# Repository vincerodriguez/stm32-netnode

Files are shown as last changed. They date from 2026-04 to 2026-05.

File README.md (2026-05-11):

# stm32-netnode

Usb powered stm32f407-based board that reports temperature and telemetry data over ethernet. BME688 is used for the temp sensor, with 1MB flash. SPI and I2C connectors for something in the future, good to have. 
## Status

- [x] Schematic complete
- [x] PCB layout complete  
- [x] v1 boards ordered from JLCPCB (2026-04-19)
- [x] Bring-up
- [x] Firmware MVP
- [x] Deployment

## Specs

| | |
|---|---|
| MCU | STM32F407VET6 (Cortex-M4F @ 168 MHz, 512 KB flash, 192 KB SRAM, 100-LQFP) |
| Ethernet PHY | Microchip LAN8720A, RMII |
| Magjack | Pulse J0011D01BNL |
| Sensor | Bosch BME688 (temperature, humidity, pressure, VOC) |
| Storage | Winbond W25Q80DVUXIE SPI NOR, 8 MBIT (1MB) |
| Power | USB-C, 5 V → 3.3 V via AP2112K-3.3 LDO |
| PCB | 60 × 60 mm, 4-layer, JLCPCB |
| Firmware | C - LWIP, ST-HAL (planned port to Rust) |

## Repo layout
hardware/ KiCad project structure
docs/ Design documentation and ADRs
firmware/ C firmware / Rust (coming soon)
test/ Bring-up checklists and general bring-up headaches

## Documents

- [Requirements](docs/01-design.md) *(coming)*
- [Architecture](docs/02-architecture.md) 
- [Decision records](docs/03-bringup-analysis.md) *(coming)*

## License

MIT

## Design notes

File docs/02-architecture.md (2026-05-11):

# Architecture

This document describes the architecture and firmware design for the stm32-netnode. See the [Design Decisions](01-design.md) for the *why* specific parts and patterns were chosen. For the story of how it actually came up, see [Bring-up Analysis](03-bringup-analysis.md).

---

## Hardware block diagram

MCU ->  ETHERNET
    |
    --> FLASH
    |
    --> TEMPERATURE
    |
    --> CONNECTIVITY (SWD/UART/I2C/SPI)
5V(USB) -> 3.3V LDO -> (MCU/PHY/FLASH/TEMP)

See hardware/[schematic.pdf]

## Subsystems

### Power

The boards main power input is 5V from USB-C. The AP2112K-3.3 max current is 600mA. We can safely assume the MCU and peripherals will pull much less than that, and will be safely below the 600mA limit of the AP2112K-3.3. 
Power estimation:
MCU: 100-150mA
PHY: 50-70mA
Temp Sensor: 3-12mA
Flash 5-15mA
Misc(LED/GPIO) 10-20mA
Then we could shoot for a max current consumption of around 270mA.
So if we design around the peak consumption of 270mA with every device being pushed to its limit we have around a 1.7V drop across the LDO, with dissipation being 459mW. At about 184°C/W for the SOT-25 package from the LDO datasheet, that gives around an 84.5°C rise above ambient. This will push the junction temp to around 110°C which is close to the absolute max of 125°C. With sufficient copper given to the LDO this should be manageable. For a later revision, a switching regulator would be a better choice if we add more peripherals and functionality.  

### Ethernet

I've used the LAN8720 in many designs before its selection was a no-brainer. The STM23F407 has a 10/100 Ethernet MAC, with RMII support, which will cut down on the number of pins. The LAN8720 supports 100Mbps and RMII. The PHY has distinct clocking configurations, you can either give it a 25MHz clock, and have it generate a 50Mhz reference to the MCU, or you can supply both the MCU and PHY a 50Mhz reference. For simplicity, and to choose a path I've known to work in the past, I chose the former. For the physical side, the J0011D01BNL with integrated magnetics is sufficient, as it will cut down on board space, since a dedicated magnetics component would not be needed, and it is used in the LAN8720 reference design.

### Storage

A modest 1MB (8Mbit) serial NOR flash is availiable for future logging or data storage. The price and availability of memory these seems to be continuing to rise, so a relatively cheap part is chosen, the W25Q80DVUXIE. Whichever SPI peripheral is available and makes routing the easiest is the best approach here. 

### Sensor

For the main purpose of the board, a popular and relatively cheap temperature/humidity/baro sensor is a great fit. The communication interface is I2C, with the address hard-coded by pullups/downs on specific pins (CSB pulled high chooses 0x77). Sensor readings don't have to be the fastest, so around 1Hz will be more than enough for a passive ambient room monitor. 

### Debug & programming

Main programmin interface will be a SWD header, with SWCLK, SWDIO, GND and RESET pins exposed. This allows debugging at the Cortex-M core. USB data will also be routed to the dedicated USB interface pins for DFU programming. UART DFU pins will not be routed, but perhaps will be in a future revision. DFU can be difficult based on previous designs. 

---

## Firmware architecture

Firmware will be first brought-up using STM's CubeMX generator. This will provide a basis for organization and STM's own HAL libraries. The Lightweight IP stack will be perfect for this boards intentions. There will need to be some dedicated review on how it works on my part, with the help of Claude code of course. Evetually the task will turn into porting over the firmware to Rust.  

### Overall structure

The big picture is that the firmware reads the temperature sensor once every second and serves the data as JSON over a raw LwIP HTTP server. Claude code was used to create a good-looking web dashboard that allows you to select which sensor reading you want displayed over time. The mainloop drives the TCP/IP stack takes in command line input from a UART connection to a PC, and reads the temperature sensor. 

### Module layout

```
firmware/Core/src/
├── main.c              # Main loop, init sequence
├── bme68x_driver.c     # Temp sensor driver using API  
├── bme68x.c            # Official Bosche API
├── cli.c               # Serial console command line driver 
├── http_server.c       # Claude-generated HTTP server 
├── lan8720.c           # PHY application API 
├── sensor_data.c       # Simple sensor API implementation
├── w25q80.c            # SPI NOR driver
```
### Concurrency model

Priority is implicit here, each call gets its own CPU time, no interrupts and no OS. Simple enough for a hardware engineer. Each process has to finish before the next gets a chance to do what it does. If a TCP packet arrives while the temp sensor is sending data it has to wait until Sensor_Poll() returns. The ethernet interface has a DMA FIFO so while other tasks are running the queue gets filled, but it's very inlikely that it will get full and drop packets before the loop comes back around and the ISR drains it. Perhaps if a sensor read takes a extrememly large amount of time to return, some packets might be dropped, but a coupple sensor readings a couple seconds apart being dropped does not matter in the grans scheme of this design. 

### Interrupt usage

The only interrupt driven process in this design is the ethernet DMA engine. TCP packets fill a RX buffer and it gets processed when the MX_LWIP_Process() gets called. The command line UART interface and temperature sensor readings are all blocking. You may notice some dropped input characters. The heartbeat LED would be the biggest indicator that something took longer than expected since its update is in the same loop as the blocking processes. 

### HTTP server

The HTTP server serves a html dashboard, sensor readings an JSON and the ability to toggle the gas sensor on or off to eliminated the temperature reading drift. Perhaps this could be optimized to be stored in the on-board flash, as it takes up about 7KB in the MCU flash. This does contribute to less SRAM footprint during the MCU runtime, but less MCU flash usage as well will be even better. The biggest RAM consumption would be the TCP RX buffers which would take up around 20-30KB. With 512KB of flash and 192KB of SRAM I have plenty of headroom.

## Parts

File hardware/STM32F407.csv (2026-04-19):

Id | Designator | Footprint | Quantity | Designation | Supplier and ref
1 | 3.3V, ETH_CRS_DV, ETH_REF_CLK, GND, GND, VUSB | TestPoint_Pad_D1.5mm | 6 | TestPoint
2 | C1, C2, C28 | C_0603_1608Metric | 3 | 10u
3 | C3, C9, C10, C11, C12, C13, C14, C16, C17, C18, C19, C23, C24, C25, C27, C29, C30 | C_0603_1608Metric | 17 | 0.1u
4 | C4, C15, C26 | C_0805_2012Metric | 3 | 4.7u
5 | C5, C6, C21, C22 | C_0603_1608Metric | 4 | 27pF
6 | C7, C8 | C_0603_1608Metric | 2 | 2u2
7 | C20 | C_0603_1608Metric | 1 | 0.022u 50V
8 | D1, D2 | LED_0603_1608Metric | 2 | LED
9 | D3 | LED_0603_1608Metric | 1 | POWER
10 | D4 | LED_0603_1608Metric | 1 | USER
11 | FB1 | L_0201_0603Metric | 1 | FerriteBead
12 | J1 | USB4110-GF-A_GCT | 1 | USB4110-GF-A
13 | J2 | CONN12_011D01BNL_PUL | 1 | J0011D01BNL
14 | J4 | PinHeader_2x10_P2.54mm_Vertical_SMD | 1 | Breakout
15 | R1, R2, R12, R15, R16, R17, R18, R26, R27 | R_0603_1608Metric | 9 | 10k
16 | R3, R4, R29, R30 | R_0603_1608Metric | 4 | 4.7k
17 | R6 | R_0603_1608Metric | 1 | 0
18 | R7, R8, R9, R10 | R_0603_1608Metric | 4 | 49.9 1%
19 | R11, R13 | R_0603_1608Metric | 2 | 270
20 | R14 | R_0603_1608Metric | 1 | 12.4k
21 | R19, R20, R21, R22, R23, R24, R25 | R_0603_1608Metric | 7 | 33
22 | R28 | R_0603_1608Metric | 1 | 1k
23 | R31, R32, R34, R35 | R_0603_1608Metric | 4 | 220
24 | R33, R38 | R_0603_1608Metric | 2 | 1.5k
25 | R36, R37 | R_0603_1608Metric | 2 | 5.1k
26 | SW1, SW2 | SW_7914J-1-000E | 2 | 7914J-1-000E
27 | U1 | LQFP-100_14x14mm_P0.5mm | 1 | STM32F407VETx
28 | U2 | Winbond_USON-8-1EP_3x2mm_P0.5mm_EP0.2x1.6mm | 1 | W25Q25PWSSIQ
29 | U3 | VQFN-24-1EP_4x4mm_P0.5mm_EP2.5x2.5mm_ThermalVias | 1 | LAN8720A
30 | U4 | IC_BME688 | 1 | BME688
31 | U5 | SILABS_CP2102N-A02-GQFN20R | 1 | CP2102N-A02-GQFN20R
32 | U6 | SOT-23-5 | 1 | AP2112K-3.3
33 | U7 | SOT-666 | 1 | USBLC6-2P6
34 | Y1 | Crystal_SMD_HC49-SD | 1 | 8MHz
35 | Y2 | Crystal_SMD_Abracon_ABM3B-4Pin_5.0x3.2mm | 1 | ABM3B-25.000MHZ-B2-T

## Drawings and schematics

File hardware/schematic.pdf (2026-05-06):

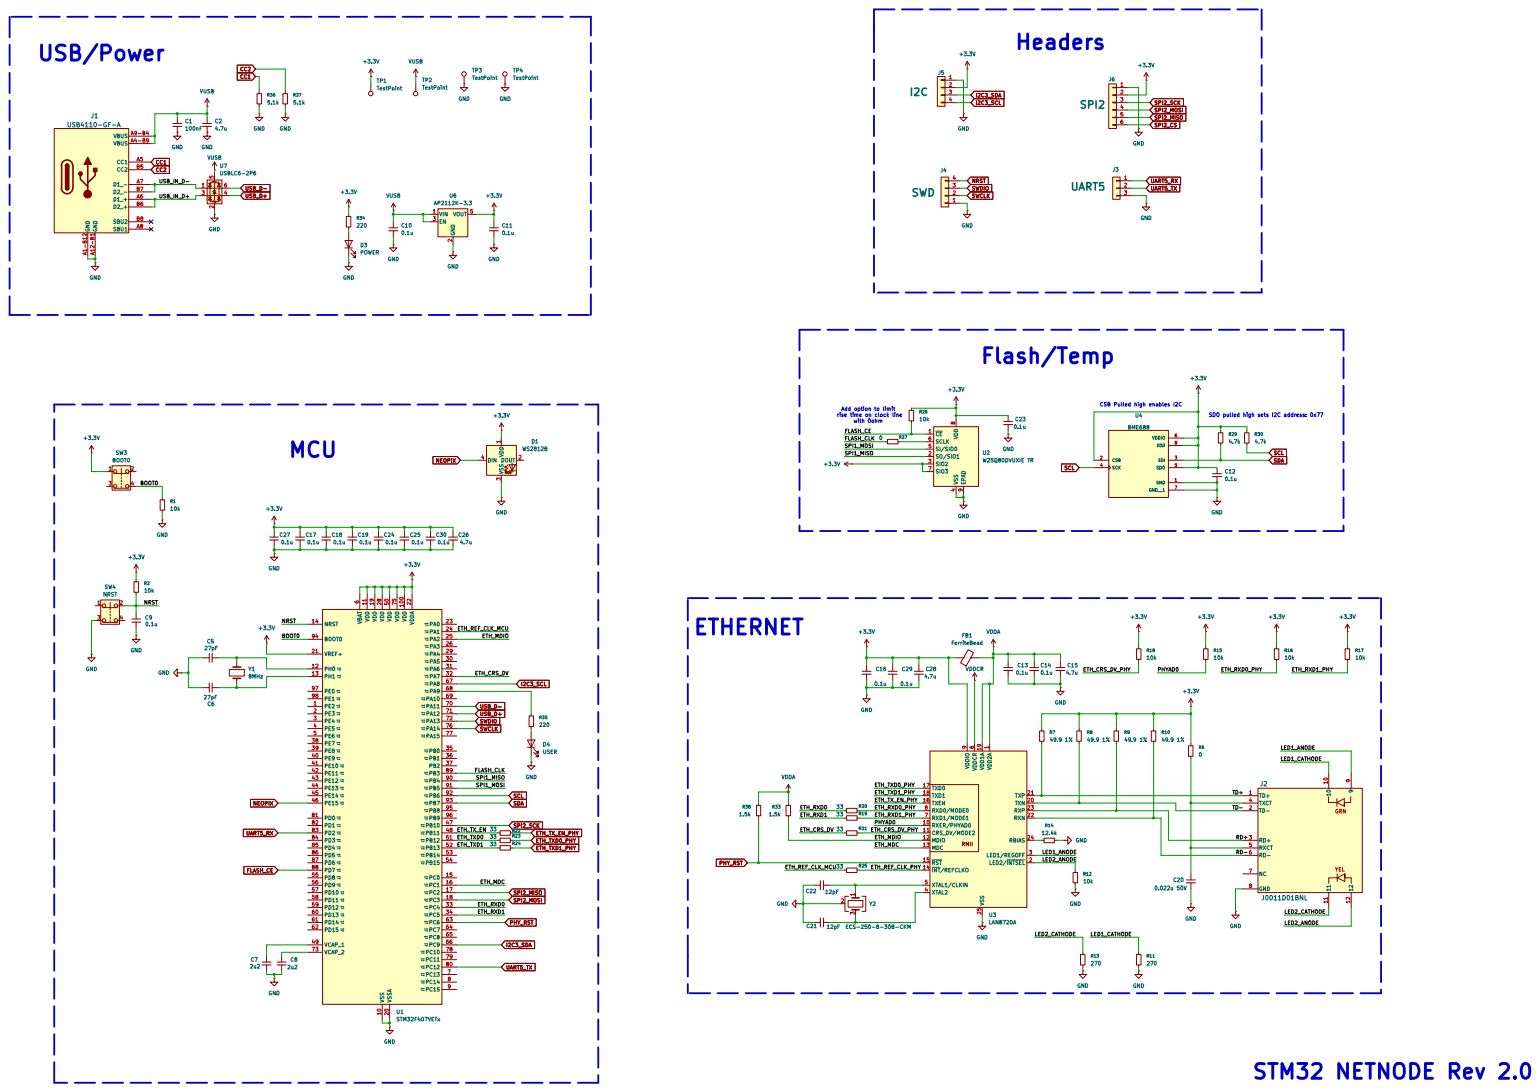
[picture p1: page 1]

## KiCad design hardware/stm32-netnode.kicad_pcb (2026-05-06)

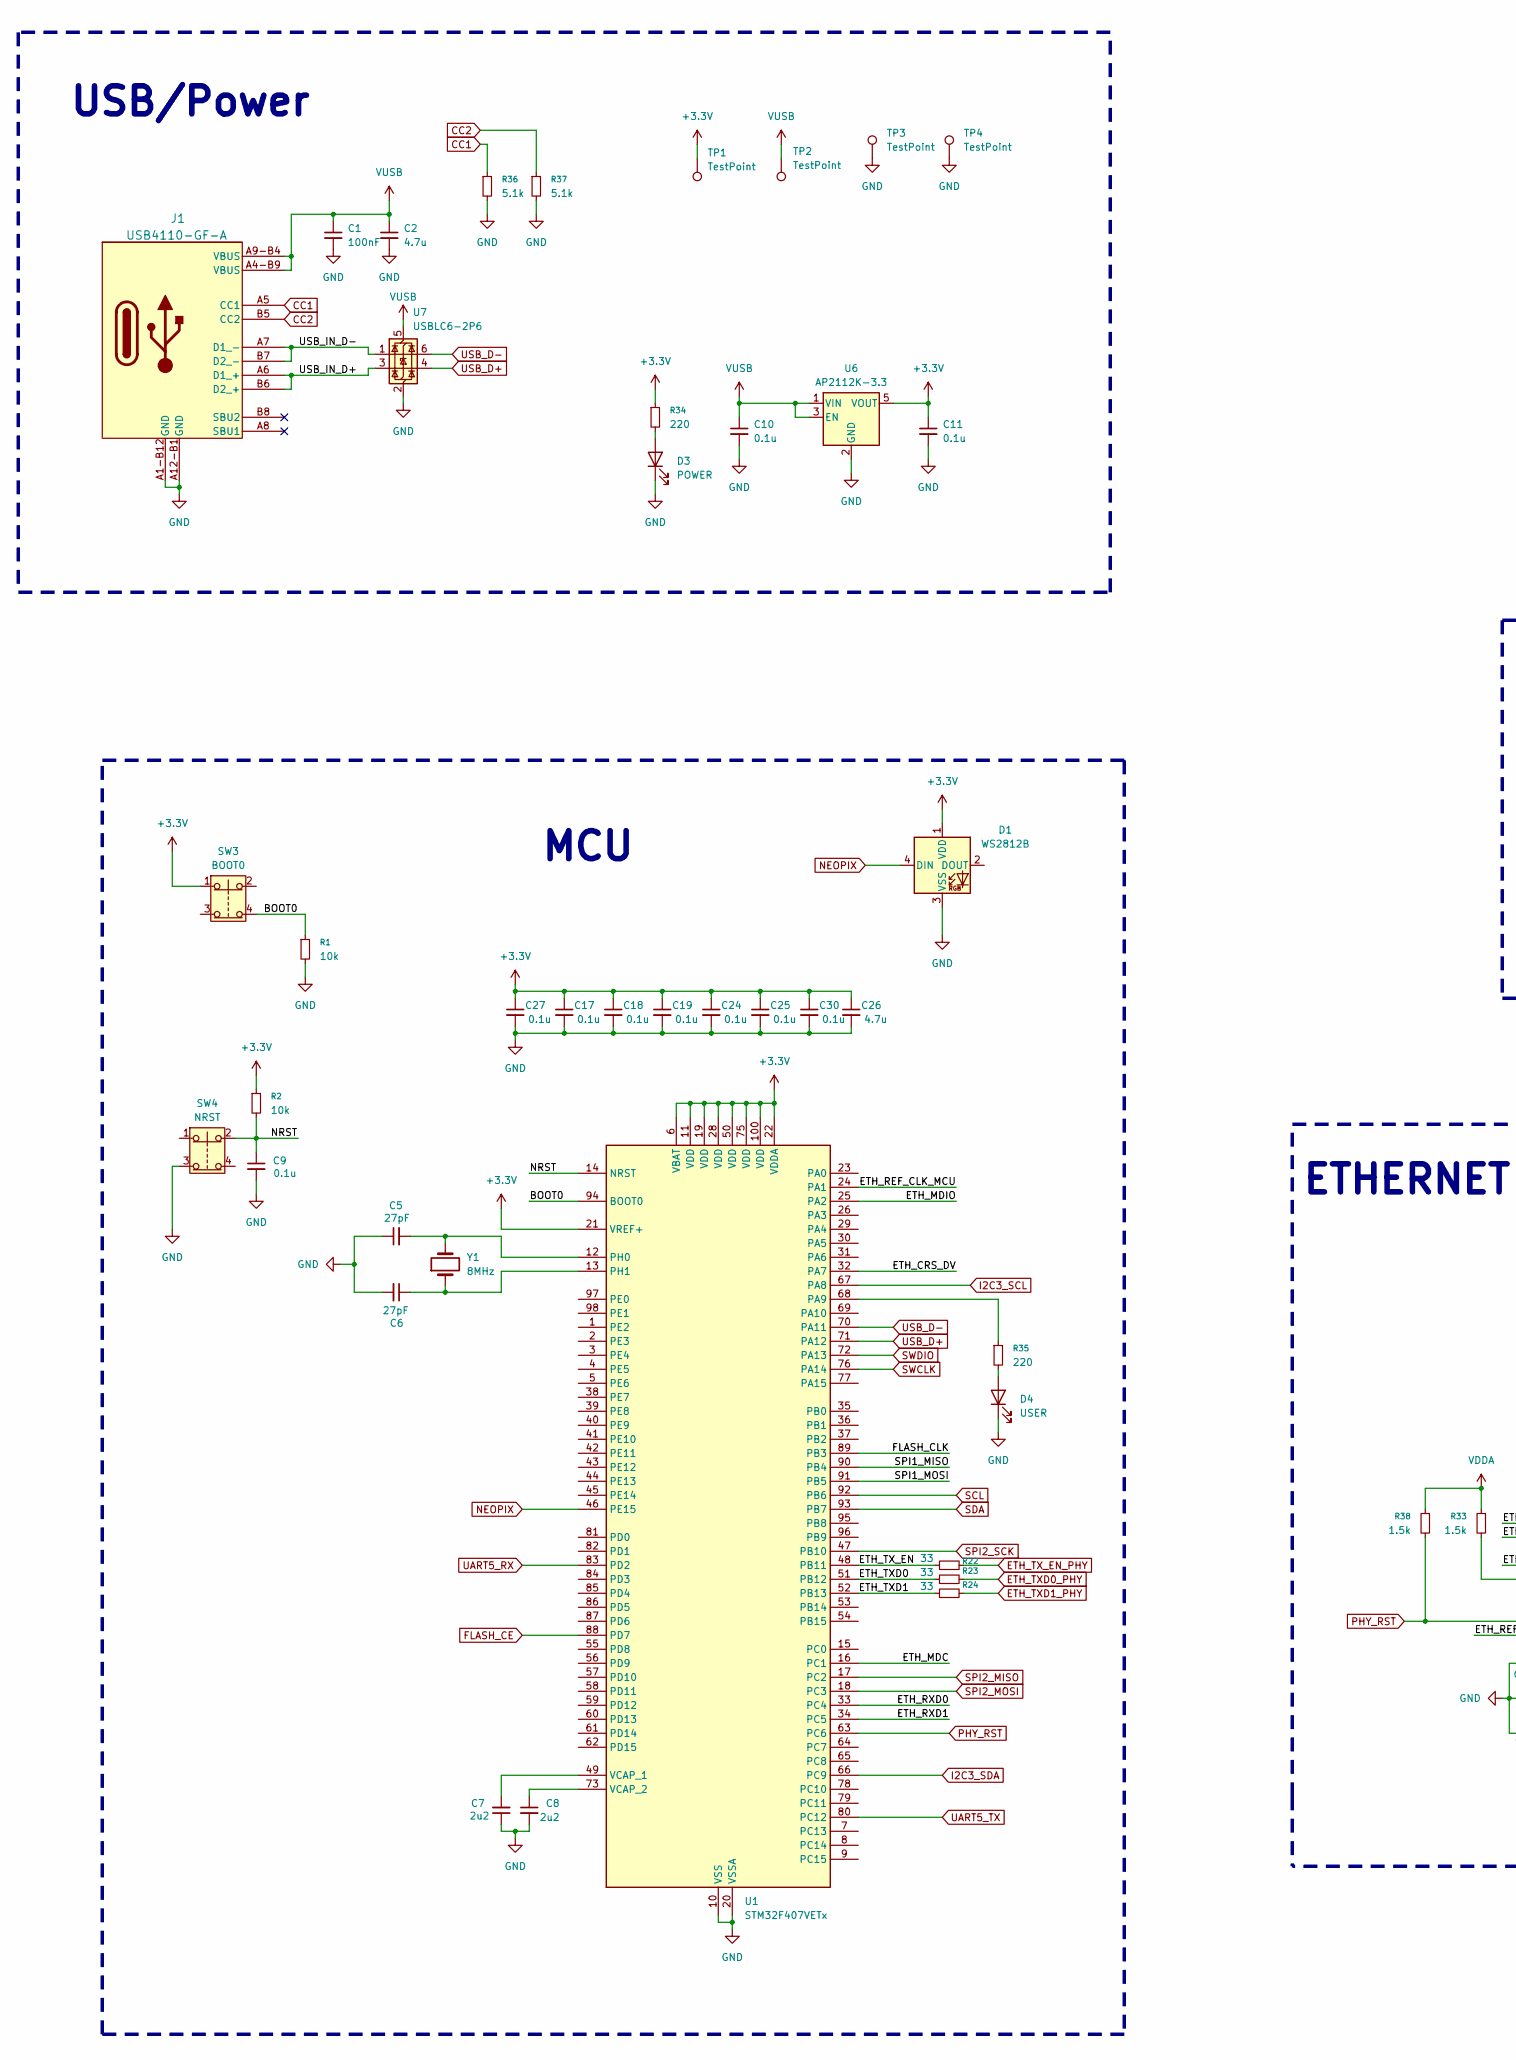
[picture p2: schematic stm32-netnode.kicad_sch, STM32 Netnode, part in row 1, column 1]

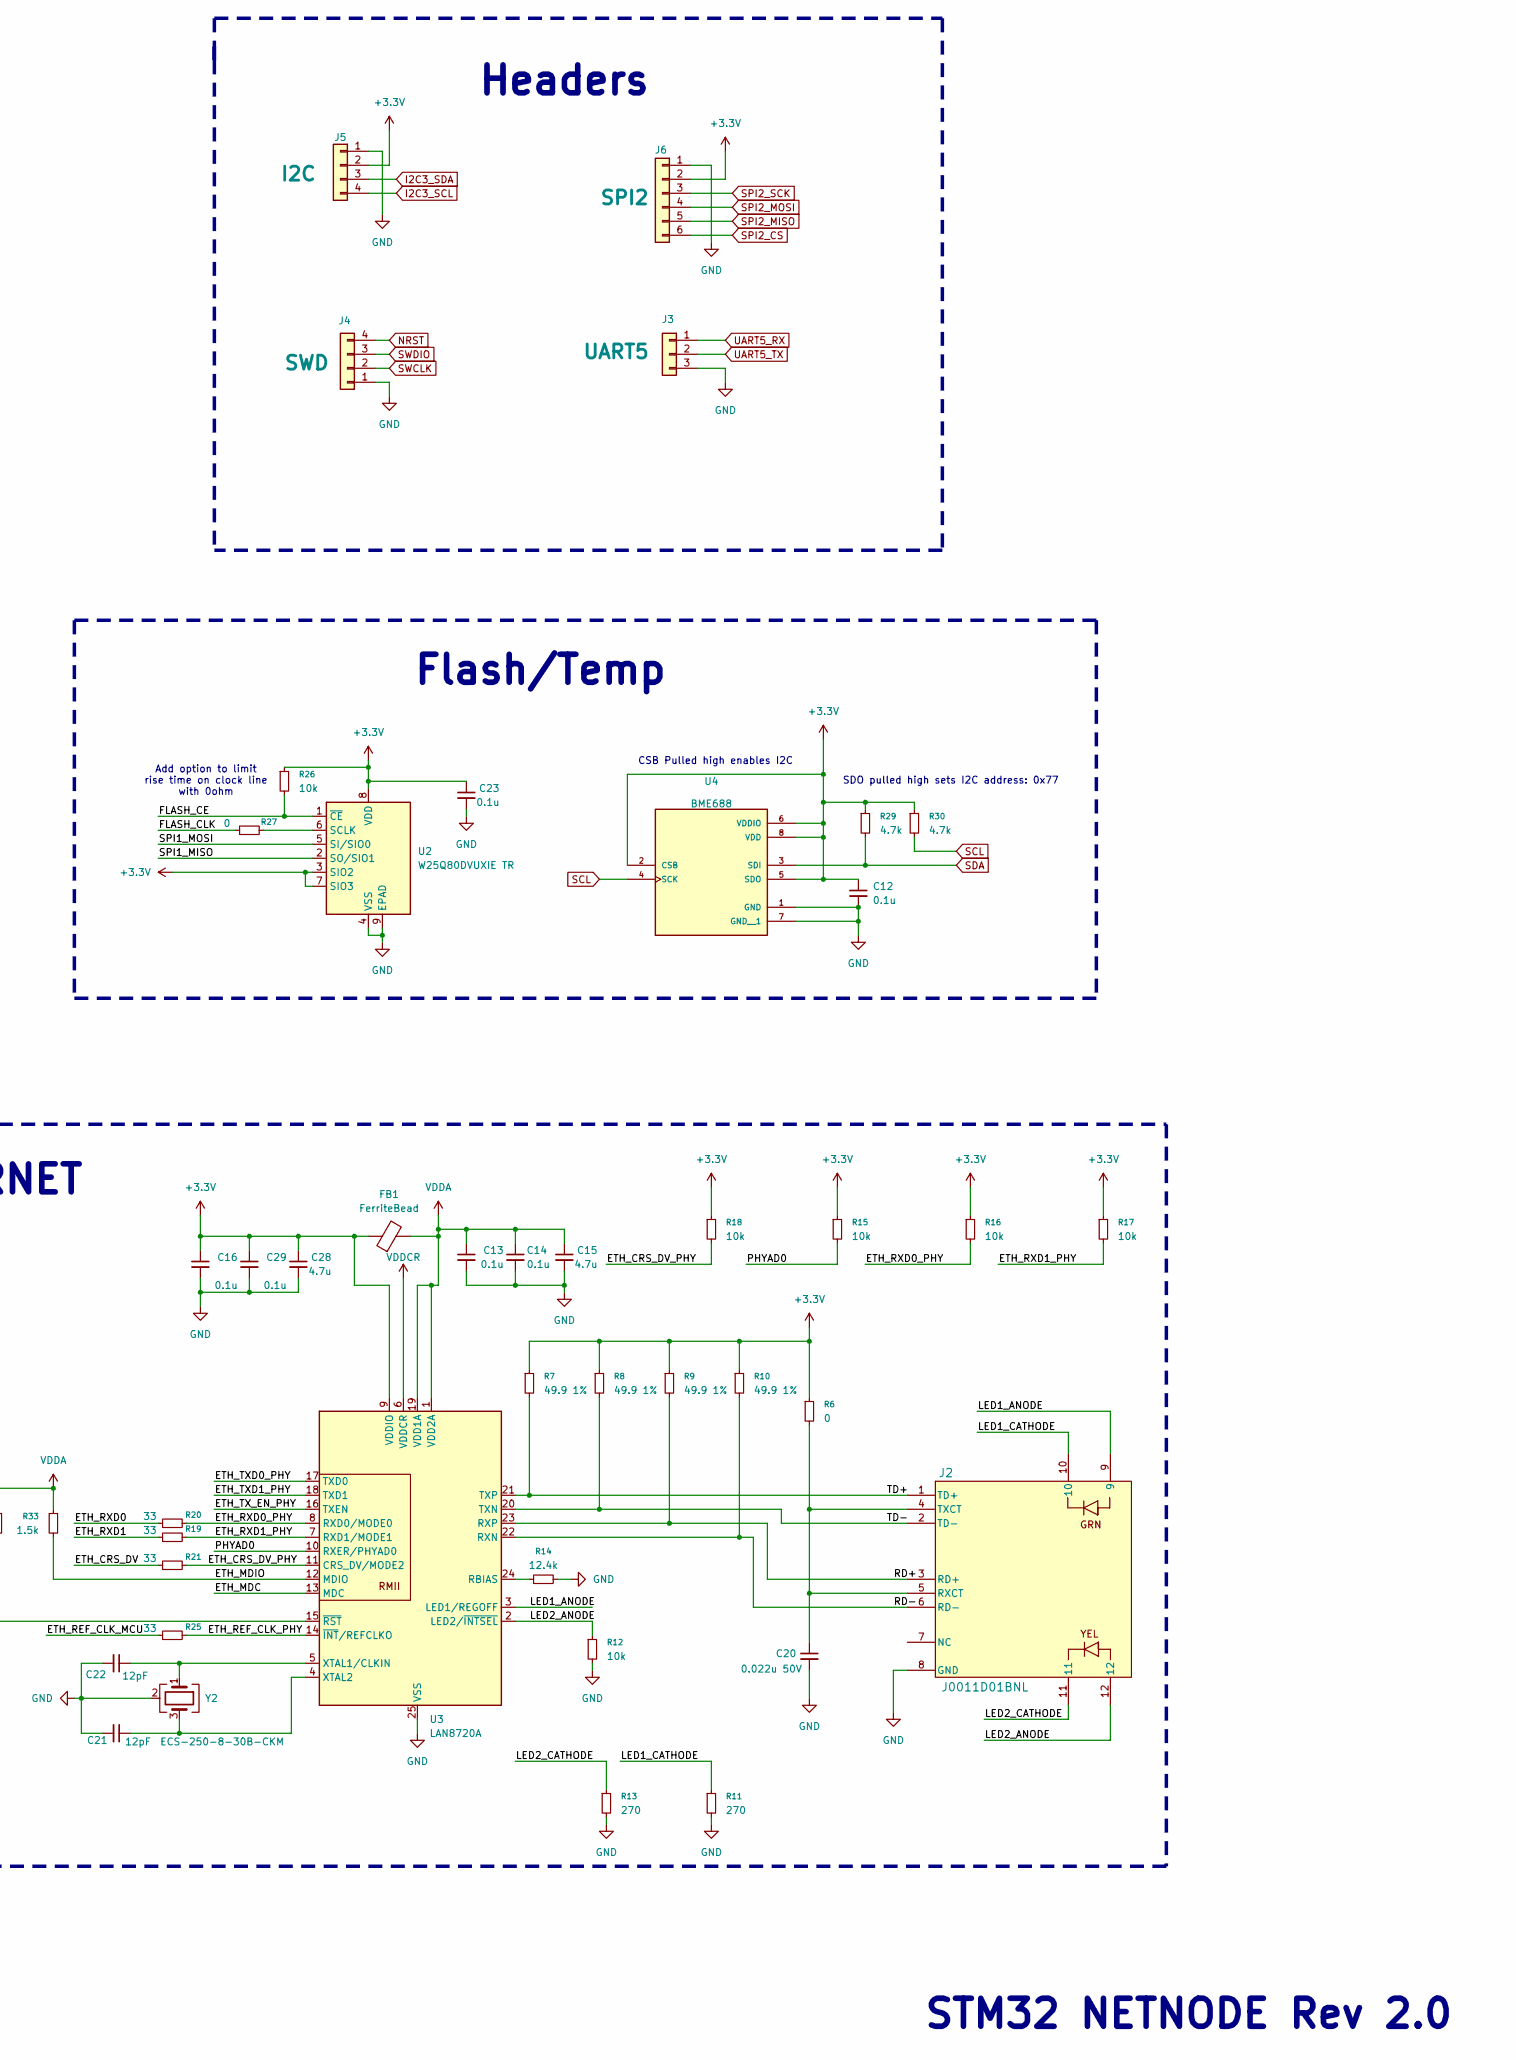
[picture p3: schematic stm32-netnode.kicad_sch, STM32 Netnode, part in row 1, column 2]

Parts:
C1: 100nF; C_0603_1608Metric
C2: 4.7u; C_0603_1608Metric
C5, C6: 27pF; C_0603_1608Metric
C7, C8: 2u2; C_0603_1608Metric
C9, C10, C11, C12, C13, C14, C16, C17, C18, C19, C23, C24, C25, C27, C29, C30: 0.1u; C_0603_1608Metric
C15, C26, C28: 4.7u; C_0805_2012Metric
C20: 0.022u 50V; C_0603_1608Metric
C21, C22: 12pF; C_0402_1005Metric
D1: WS2812B; LED_WS2812B_PLCC4_5.0x5.0mm_P3.2mm
D3: POWER; LED_0603_1608Metric
D4: USER; LED_0603_1608Metric
FB1: FerriteBead; L_0603_1608Metric
J1: USB4110-GF-A; USB4110-GF-A_GCT
J2: J0011D01BNL; CONN12_011D01BNL_PUL
J3: UART5; PinHeader_1x03_P2.54mm_Vertical
J4: SWD; PinHeader_1x04_P2.54mm_Vertical
J5: I2C; CONN4_BM04B-SRSS_JST
J6: SPI2; CONN_BM06B-SRSS-TB_JST
R1, R2, R12, R15, R16, R17, R18, R26: 10k; R_0603_1608Metric
R6, R27: 0; R_0603_1608Metric
R7, R8, R9, R10: 49.9 1%; R_0603_1608Metric
R11, R13: 270; R_0603_1608Metric
R14: 12.4k; R_0603_1608Metric
R19, R20, R21, R22, R23, R24, R25: 33; R_0603_1608Metric
R29, R30: 4.7k; R_0603_1608Metric
R33, R38: 1.5k; R_0603_1608Metric
R34, R35: 220; R_0603_1608Metric
R36, R37: 5.1k; R_0603_1608Metric
SW3: BOOT0; SW_7914J-1-000E
SW4: NRST; SW_7914J-1-000E
TP1, TP2, TP3, TP4: TestPoint; TestPoint_Pad_D1.5mm
U1: STM32F407VETx; LQFP-100_14x14mm_P0.5mm
U2: W25Q80DVUXIE TR; Winbond_USON-8-1EP_3x2mm_P0.5mm_EP0.2x1.6mm
U3: LAN8720A; VQFN-24-1EP_4x4mm_P0.5mm_EP2.5x2.5mm_ThermalVias
U4: BME688; IC_BME688; PARTREV 1.0
U6: AP2112K-3.3; SOT-23-5
U7: USBLC6-2P6; SOT-666
Y1: 8MHz; Crystal_SMD_HC49-SD
Y2: ECS-250-8-30B-CKM; XTAL_ECS-250-8-30B-CKM

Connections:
+3.3V: C11.1, C12.1, C16.1, C17.1, C18.1, C19.1, C23.1, C24.1, C25.1, C26.1, C27.1, C28.1, C29.1, C30.1, D1.1 (VDD), FB1.1, J5.2, J6.2, R2.1, R6.1, R7.1, R8.1, R9.1, R10.1, R15.1, R16.1, R17.1, R18.1, R26.1, R29.1, R30.1, R34.1, SW3.1, TP1.1 (1_1), U1.6 (VBAT), U1.11 (VDD), U1.19 (VDD), U1.21 (VREF+), U1.22 (VDDA), U1.28 (VDD), U1.50 (VDD), U1.75 (VDD), U1.100 (VDD), U2.3 (SIO2), U2.7 (SIO3), U2.8 (VDD), U3.9 (VDDIO), U4.2 (CSB), U4.5 (SDO), U4.6 (VDDIO), U4.8 (VDD), U6.5 (VOUT)
/BOOT0: R1.1, SW3.4, U1.94 (BOOT0)
/ETH_CRS_DV: R21.1, U1.32 (PA7)
/ETH_CRS_DV_PHY: R18.2, R21.2, U3.11 (CRS_DV/MODE2)
/ETH_MDC: U1.16 (PC1), U3.13 (MDC)
/ETH_MDIO: R33.2, U1.25 (PA2), U3.12 (MDIO)
/ETH_REF_CLK_MCU: R25.1, U1.24 (PA1)
/ETH_REF_CLK_PHY: R25.2, U3.14 (~INT/REFCLKO)
/ETH_RXD0: R20.1, U1.33 (PC4)
/ETH_RXD0_PHY: R16.2, R20.2, U3.8 (RXD0/MODE0)
/ETH_RXD1: R19.1, U1.34 (PC5)
/ETH_RXD1_PHY: R17.2, R19.2, U3.7 (RXD1/MODE1)
/ETH_TXD0: R23.1, U1.51 (PB12)
/ETH_TXD1: R24.1, U1.52 (PB13)
/ETH_TX_EN: R22.1, U1.48 (PB11)
/FLASH_CLK: R27.1, U1.89 (PB3)
/LED1_ANODE: J2.9, U3.3 (LED1/REGOFF)
/LED1_CATHODE: J2.10, R11.1
/LED2_ANODE: J2.12, R12.1, U3.2 (LED2/~INTSEL)
/LED2_CATHODE: J2.11, R13.1
/PHYAD0: R15.2, U3.10 (RXER/PHYAD0)
/RD+: J2.3 (RD+), R9.2, U3.23 (RXP)
/RD-: J2.6 (RD-), R10.2, U3.22 (RXN)
/SPI1_MISO: U1.90 (PB4), U2.2 (SO/SIO1)
/SPI1_MOSI: U1.91 (PB5), U2.5 (SI/SIO0)
/TD+: J2.1 (TD+), R7.2, U3.21 (TXP)
/TD-: J2.2 (TD-), R8.2, U3.20 (TXN)
/USB_IN_D+: J1.A6 (D1_+), J1.B6 (D2_+), U7.3 (I/O2)
/USB_IN_D-: J1.A7 (D1_-), J1.B7 (D2_-), U7.1 (I/O1)
CC1: J1.A5 (CC1), R36.1
CC2: J1.B5 (CC2), R37.1
ETH_TXD0_PHY: R23.2, U3.17 (TXD0)
ETH_TXD1_PHY: R24.2, U3.18 (TXD1)
ETH_TX_EN_PHY: R22.2, U3.16 (TXEN)
FLASH_CE: R26.2, U1.88 (PD7), U2.1 (~CE)
GND: C1.2, C2.2, C5.1, C6.2, C7.1, C8.2, C9.2, C10.2, C11.2, C12.2, C13.2, C14.2, C15.2, C16.2, C17.2, C18.2, C19.2, C20.2, C21.2, C22.2, C23.2, C24.2, C25.2, C26.2, C27.2, C28.2, C29.2, C30.2, D1.3 (VSS), D3.1 (K), D4.1 (K), J1.A1-B12 (GND), J1.A12-B1 (GND), J2.8 (GND), J3.3, J4.1, J5.1, J6.1, R1.2, R11.2, R12.2, R13.2, R14.2, R36.2, R37.2, SW4.3, TP3.1 (1_1), TP4.1 (1_1), U1.10 (VSS), U1.20 (VSSA), U1.27 (VSS), U1.74 (VSS), U1.99 (VSS), U2.4 (VSS), U2.9 (EPAD), U3.25 (VSS), U4.1 (GND), U4.7 (GND__1), U6.2 (GND), U7.2 (GND), Y2.2 (G), Y2.4 (G)
I2C3_SCL: J5.4, U1.67 (PA8)
I2C3_SDA: J5.3, U1.66 (PC9)
NEOPIX: D1.4 (DIN), U1.46 (PE15)
NRST: C9.1, J4.4, R2.2, SW4.2, U1.14 (NRST)
unnamed: D3.2 (A), R34.2
unnamed: D4.2 (A), R35.2
unnamed: C20.1, J2.4 (TXCT), J2.5 (RXCT), R6.2
unnamed: R35.1, U1.68 (PA9)
unnamed: C5.2, U1.12 (PH0), Y1.2
unnamed: C6.1, U1.13 (PH1), Y1.1
unnamed: C7.2, U1.49 (VCAP_1)
unnamed: C8.1, U1.73 (VCAP_2)
unnamed: R27.2, U2.6 (SCLK)
unnamed: R14.1, U3.24 (RBIAS)
unnamed: C22.1, U3.5 (XTAL1/CLKIN), Y2.1
unnamed: C21.1, U3.4 (XTAL2), Y2.3
PHY_RST: R38.2, U1.63 (PC6), U3.15 (~RST)
SCL: R30.2, U1.92 (PB6), U4.4 (SCK)
SDA: R29.2, U1.93 (PB7), U4.3 (SDI)
SPI2_CS: J6.6
SPI2_MISO: J6.5, U1.17 (PC2)
SPI2_MOSI: J6.4, U1.18 (PC3)
SPI2_SCK: J6.3, U1.47 (PB10)
SWCLK: J4.2, U1.76 (PA14)
SWDIO: J4.3, U1.72 (PA13)
UART5_RX: J3.1, U1.83 (PD2)
UART5_TX: J3.2, U1.80 (PC12)
USB_D+: U1.71 (PA12), U7.4 (I/O2)
USB_D-: U1.70 (PA11), U7.6 (I/O1)
VDDA: C13.1, C14.1, C15.1, FB1.2, R33.1, R38.1, U3.1 (VDD2A), U3.19 (VDD1A)
VDDCR: U3.6 (VDDCR)
VUSB: C1.1, C2.1, C10.1, J1.A4-B9 (VBUS), J1.A9-B4 (VBUS), TP2.1 (1_1), U6.1 (VIN), U6.3 (EN), U7.5 (VBUS)

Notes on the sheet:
ETHERNET
CSB Pulled high enables I2C
Flash/Temp
SDO pulled high sets I2C address: 0x77
USB/Power
STM32 NETNODE Rev 2.0
Add option to limit rise time on clock line with 0ohm
Headers
MCU

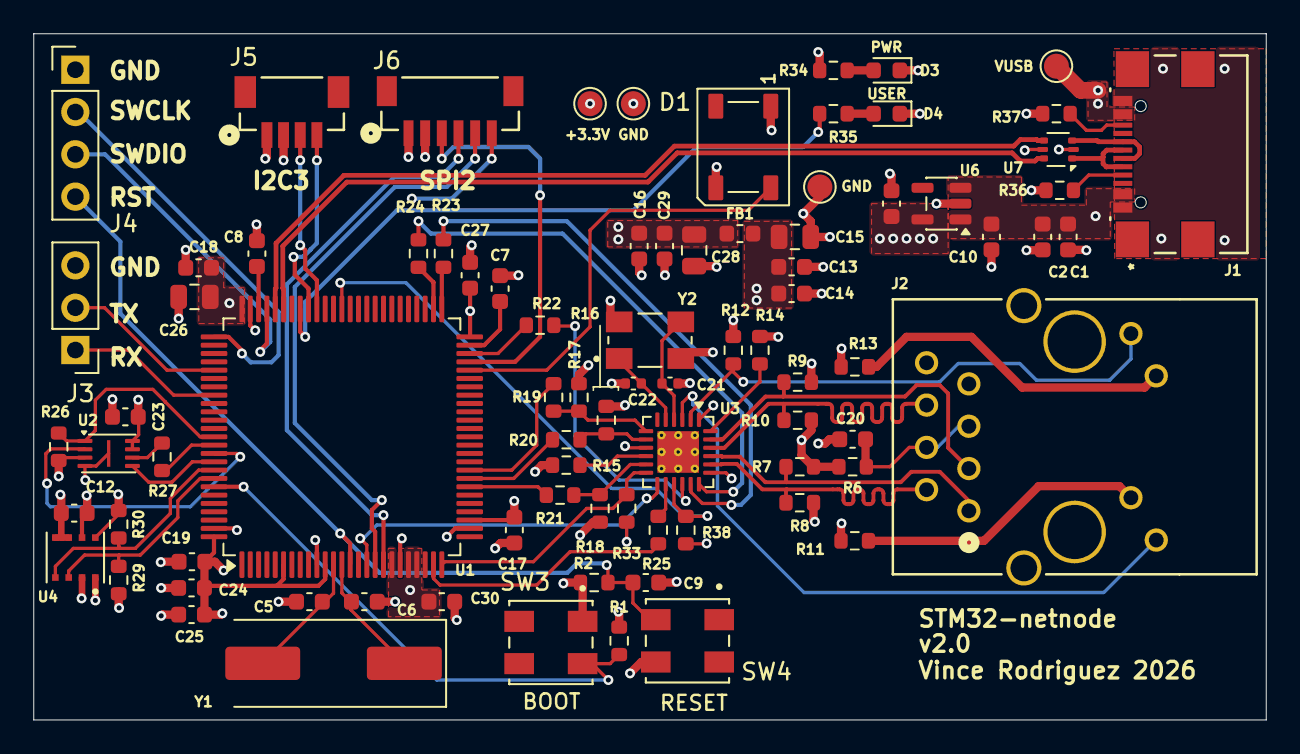
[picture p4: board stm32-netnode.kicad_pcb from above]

Board: 4 copper layers, 74.0 x 41.2 mm, 84 parts (0 on the bottom side), 66 nets.

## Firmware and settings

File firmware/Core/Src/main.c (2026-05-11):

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
/* Includes ------------------------------------------------------------------*/
#include "main.h"
#include "lwip.h"
#include "w25q80.h"
#include "cli.h"
#include "sensor_data.h"
#include "http_server.h"
#include <stdio.h>

/* USER CODE BEGIN PD */
extern SPI_HandleTypeDef hspi1;
extern UART_HandleTypeDef huart5;
extern I2C_HandleTypeDef hi2c1;

#define BME688_I2C_ADDR_7BIT   0x77
#define BME688_I2C_ADDR_8BIT   (BME688_I2C_ADDR_7BIT << 1)  // HAL uses 8-bit form
#define BME688_REG_CHIP_ID     0xD0
#define BME688_EXPECTED_ID     0x61

/* USER CODE END PD */

I2C_HandleTypeDef hi2c1;

SPI_HandleTypeDef hspi1;

UART_HandleTypeDef huart5;

void SystemClock_Config(void);
static void MX_GPIO_Init(void);
static void MX_SPI1_Init(void);
static void MX_I2C1_Init(void);
static void MX_UART5_Init(void);
/* USER CODE BEGIN 0 */

int __io_putchar(int ch)
{
	HAL_UART_Transmit(&huart5, (uint8_t *)&ch, 1, HAL_MAX_DELAY);
	return ch;
}

int _write(int file, char *ptr, int len)
{
	HAL_UART_Transmit(&huart5, (uint8_t *)ptr, len, HAL_MAX_DELAY);
	return len;
}

void BME688_AliveTest(void) {
    HAL_StatusTypeDef s;
    uint8_t chip_id = 0;

    // 1. Is the device even on the bus?
    s = HAL_I2C_IsDeviceReady(&hi2c1, BME688_I2C_ADDR_8BIT, 3, 100);
    if (s != HAL_OK) {
        printf("BME688 not responding at 0x%02X (status=%d)\r\n",
               BME688_I2C_ADDR_7BIT, s);
        printf("  -> Check: CSB tied high? SDO tied high? Pull-ups present?\r\n");
        printf("  -> I2C1 error state: 0x%08lX\r\n", HAL_I2C_GetError(&hi2c1));
        return;
    }
    printf("BME688 responding at 0x%02X\r\n", BME688_I2C_ADDR_7BIT);

    // 2. Read chip ID register 0xD0
    s = HAL_I2C_Mem_Read(&hi2c1,
                         BME688_I2C_ADDR_8BIT,
                         BME688_REG_CHIP_ID,
                         I2C_MEMADD_SIZE_8BIT,
                         &chip_id, 1, 100);
    if (s != HAL_OK) {
        printf("Chip ID read failed (status=%d, err=0x%08lX)\r\n",
               s, HAL_I2C_GetError(&hi2c1));
        return;
    }

    printf("Chip ID: 0x%02X ", chip_id);
    if (chip_id == 0x61) {
        printf("-> BME688 confirmed\r\n");
    } else if (chip_id == 0x60) {
        printf("-> This is a BME680, not a 688\r\n");
    } else if (chip_id == 0x58) {
        printf("-> This is a BMP280 (T+P only, no humidity/gas)\r\n");
    } else if (chip_id == 0xFF || chip_id == 0x00) {
        printf("-> Invalid response, bus likely floating\r\n");
    } else {
        printf("-> Unknown chip at this address\r\n");
    }
}

/* USER CODE END 0 */

/**
  * @brief  The application entry point.
  * @retval int
  */
int main(void)
{

  /* MCU Configuration--------------------------------------------------------*/

  /* Reset of all peripherals, Initializes the Flash interface and the Systick. */
  HAL_Init();

  /* Configure the system clock */
  SystemClock_Config();

  /* Initialize all configured peripherals */
  MX_GPIO_Init();
  MX_SPI1_Init();
  MX_I2C1_Init();
  MX_UART5_Init();

  setvbuf(stdout, NULL, _IONBF, 0);

  /* USER CODE BEGIN SysInit */
  /* Pulse PHY reset */
  HAL_GPIO_WritePin(PHY_RST_GPIO_Port, PHY_RST_Pin, GPIO_PIN_RESET);
  HAL_Delay(10);
  HAL_GPIO_WritePin(PHY_RST_GPIO_Port, PHY_RST_Pin, GPIO_PIN_SET);
  HAL_Delay(100);
  /* USER CODE END SysInit */

  MX_LWIP_Init();

  /* USER CODE BEGIN 2 */
  Sensor_Init();
  HTTP_Server_Init();
  CLI_Init();
  /* USER CODE END 2 */

  /* Infinite loop */
  /* USER CODE BEGIN WHILE */
  uint32_t led_tick = 0;
  while (1)
  {
    /* USER CODE END WHILE */
    MX_LWIP_Process();
    CLI_Process();
    Sensor_Poll();

    if (HAL_GetTick() - led_tick >= 500) {
      HAL_GPIO_TogglePin(LED_GPIO_Port, LED_Pin);
      led_tick = HAL_GetTick();
    }

    /* USER CODE BEGIN 3 */
  }
  /* USER CODE END 3 */
}

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


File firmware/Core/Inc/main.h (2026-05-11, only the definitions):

#define FLASH_CE_Pin GPIO_PIN_7
#define FLASH_CE_GPIO_Port GPIOD
#define PHY_RST_Pin GPIO_PIN_6
#define PHY_RST_GPIO_Port GPIOC
#define LED_Pin GPIO_PIN_9
#define LED_GPIO_Port GPIOA

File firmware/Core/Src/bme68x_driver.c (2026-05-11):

#include "bme68x_driver.h"
#include "main.h"
#include <stdio.h>
#include <string.h>

extern I2C_HandleTypeDef hi2c1;

#define BME688_I2C_ADDR   0x77
#define BME688_I2C_ADDR8  (BME688_I2C_ADDR << 1)

static struct bme68x_dev  bme;
static uint8_t            dev_addr    = BME688_I2C_ADDR;
static uint8_t            gas_enabled = 1;

/* ===== Platform glue functions (Bosch driver calls these) ===== */

static BME68X_INTF_RET_TYPE bme_i2c_read(uint8_t reg, uint8_t *data,
                                          uint32_t len, void *intf_ptr)
{
    uint8_t addr = *(uint8_t*)intf_ptr;
    HAL_StatusTypeDef s = HAL_I2C_Mem_Read(&hi2c1, addr << 1, reg,
                                            I2C_MEMADD_SIZE_8BIT,
                                            data, len, HAL_MAX_DELAY);
    return (s == HAL_OK) ? BME68X_INTF_RET_SUCCESS : -1;
}

static BME68X_INTF_RET_TYPE bme_i2c_write(uint8_t reg, const uint8_t *data,
                                           uint32_t len, void *intf_ptr)
{
    uint8_t addr = *(uint8_t*)intf_ptr;
    HAL_StatusTypeDef s = HAL_I2C_Mem_Write(&hi2c1, addr << 1, reg,
                                             I2C_MEMADD_SIZE_8BIT,
                                             (uint8_t*)data, len, HAL_MAX_DELAY);
    return (s == HAL_OK) ? BME68X_INTF_RET_SUCCESS : -1;
}

static void bme_delay_us(uint32_t period, void *intf_ptr)
{
    (void)intf_ptr;
    // Cheap microsecond delay using DWT cycle counter.
    // Requires DWT to be enabled once at boot (see below).
    uint32_t start = DWT->CYCCNT;
    uint32_t ticks = period * (SystemCoreClock / 1000000U);
    while ((DWT->CYCCNT - start) < ticks) { /* spin */ }
}


int8_t BME688_Init(void)
{
    // Enable DWT cycle counter once for microsecond delays.
    // Safe to call multiple times.
    CoreDebug->DEMCR |= CoreDebug_DEMCR_TRCENA_Msk;
    DWT->CYCCNT = 0;
    DWT->CTRL  |= DWT_CTRL_CYCCNTENA_Msk;

    memset(&bme, 0, sizeof(bme));
    bme.intf       = BME68X_I2C_INTF;
    bme.read       = bme_i2c_read;
    bme.write      = bme_i2c_write;
    bme.delay_us   = bme_delay_us;
    bme.intf_ptr   = &dev_addr;
    bme.amb_temp   = 25;  // approximate ambient temp, °C (used for heater calc)

    int8_t rc = bme68x_init(&bme);
    if (rc != BME68X_OK) {
        printf("bme68x_init failed: %d\r\n", rc);
        return rc;
    }

    // Oversampling + IIR config (good defaults: indoor environment)
    struct bme68x_conf conf = {
        .os_hum  = BME68X_OS_2X,
        .os_temp = BME68X_OS_8X,
        .os_pres = BME68X_OS_4X,
        .filter  = BME68X_FILTER_SIZE_3,
        .odr     = BME68X_ODR_NONE,
    };
    rc = bme68x_set_conf(&conf, &bme);
    if (rc != BME68X_OK) { printf("set_conf: %d\r\n", rc); return rc; }

    // Heater: single-point, 320 °C for 150 ms (standard "indoor air quality" setting)
    struct bme68x_heatr_conf heatr = {
        .enable    = BME68X_ENABLE,
        .heatr_temp = 320,
        .heatr_dur  = 150,
    };
    rc = bme68x_set_heatr_conf(BME68X_FORCED_MODE, &heatr, &bme);
    if (rc != BME68X_OK) { printf("set_heatr: %d\r\n", rc); return rc; }

    printf("BME688 initialized (chip_id=0x%02X, variant=%lu)\r\n",
           bme.chip_id, (unsigned long)bme.variant_id);
    // variant_id: 0 = BME680, 1 = BME688
    return BME68X_OK;
}

int8_t BME688_SetGasEnable(uint8_t enable)
{
    gas_enabled = enable;
    struct bme68x_heatr_conf heatr = {
        .enable     = enable ? BME68X_ENABLE : BME68X_DISABLE,
        .heatr_temp = 320,
        .heatr_dur  = 150,
    };
    return bme68x_set_heatr_conf(BME68X_FORCED_MODE, &heatr, &bme);
}

int8_t BME688_ReadForced(struct bme68x_data *data)
{
    uint8_t n_fields = 0;

    int8_t rc = bme68x_set_op_mode(BME68X_FORCED_MODE, &bme);
    if (rc != BME68X_OK) return rc;

    uint32_t meas_us = bme68x_get_meas_dur(BME68X_FORCED_MODE, NULL, &bme);
    if (gas_enabled) meas_us += 150 * 1000;   /* add heater dwell only when active */
    bme_delay_us(meas_us, NULL);

    rc = bme68x_get_data(BME68X_FORCED_MODE, data, &n_fields, &bme);
    if (rc != BME68X_OK) return rc;
    if (n_fields == 0)   return -1;
    return BME68X_OK;
}

// Heater profile: 10 setpoints, scanned repeatedly in parallel mode.
// Duration values are in "heater cycles" (each cycle ≈ ms based on shared_heatr_dur).
static uint16_t heatr_temp_prof[10] = {320, 100, 100, 100, 200, 200, 200, 320, 320, 320};
static uint16_t heatr_dur_prof[10]  = {5, 2, 10, 30, 5, 5, 5, 5, 5, 5};  // multipliers

int8_t BME688_ConfigParallelHeater(void)
{
    struct bme68x_conf conf = {
        .os_hum  = BME68X_OS_1X,
        .os_temp = BME68X_OS_2X,
        .os_pres = BME68X_OS_16X,
        .filter  = BME68X_FILTER_OFF,
        .odr     = BME68X_ODR_NONE,
    };
    int8_t rc = bme68x_set_conf(&conf, &bme);
    if (rc != BME68X_OK) return rc;

    // Measurement duration of the TPH section (excluding heater) in microseconds,
    // needed so each heater step has the right total duration.
    uint32_t meas_dur_us = bme68x_get_meas_dur(BME68X_PARALLEL_MODE, &conf, &bme);

    struct bme68x_heatr_conf heatr = {
        .enable           = BME68X_ENABLE,
        .heatr_temp_prof  = heatr_temp_prof,
        .heatr_dur_prof   = heatr_dur_prof,
        .profile_len      = 10,
        // Bosch recommends shared_heatr_dur = total_cycle - meas_dur_tph.
        // Cycle length is set in ms; 140 ms is a common default.
        .shared_heatr_dur = 140 - (uint16_t)(meas_dur_us / 1000),
    };
    rc = bme68x_set_heatr_conf(BME68X_PARALLEL_MODE, &heatr, &bme);
    if (rc != BME68X_OK) return rc;

    rc = bme68x_set_op_mode(BME68X_PARALLEL_MODE, &bme);
    return rc;
}

// Read up to 3 fresh fields produced by parallel mode.
// In parallel mode the sensor FIFO may contain 0-3 results per poll.
int8_t BME688_ReadParallel(struct bme68x_data *data, uint8_t *n_fields)
{
    return bme68x_get_data(BME68X_PARALLEL_MODE, data, n_fields, &bme);
}

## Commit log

2026-04-19 Initial commit scheamtic and layout for version 1.0
    [STM32F407.csv, stm32-netnode.kicad_pcb, stm32-netnode.kicad_sch]
2026-05-06 Radd rev 2.0
    [stm32-netnode.kicad_pcb, stm32-netnode.kicad_sch]
2026-05-06 schematic rev 2.0

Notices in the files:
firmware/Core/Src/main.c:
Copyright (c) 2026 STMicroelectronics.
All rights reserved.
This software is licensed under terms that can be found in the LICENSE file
